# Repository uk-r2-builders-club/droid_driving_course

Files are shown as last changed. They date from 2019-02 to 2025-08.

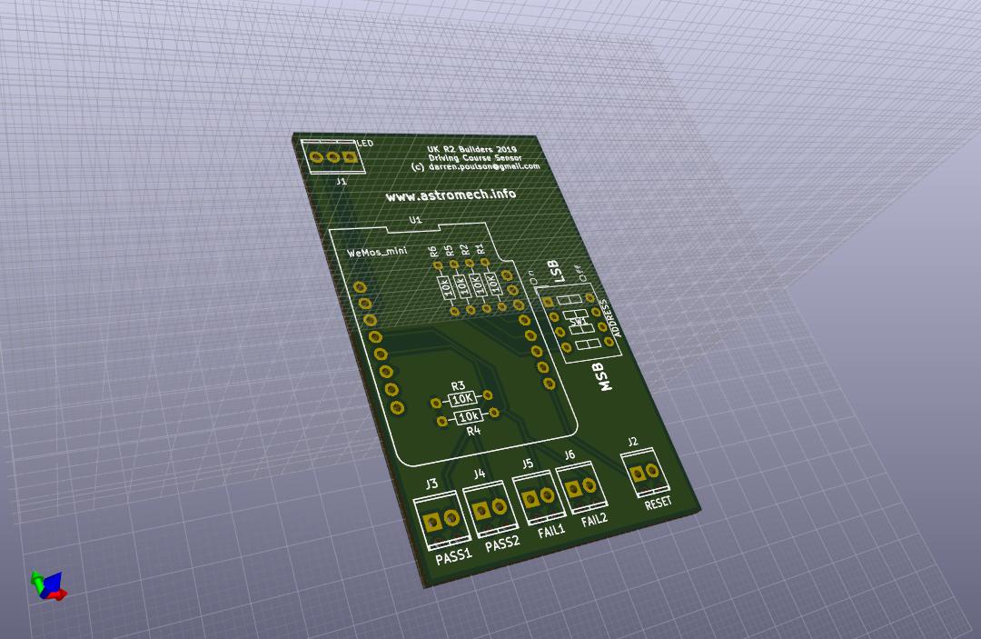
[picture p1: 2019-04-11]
Hardware/Bump Stop/bump_stop.jpg

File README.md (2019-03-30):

This adds an automatic score board system to the UK R2D2 Builders driving course

Existing wired sensors can be replaced with wireless ones, talking back to a central access point and this code running on a Pi. The Pi can have a monitor on it set up to automatically display the scoreboard.

== Installation ==

''' sudo apt-get install git python3-pip python3-future python3-flask '''

''' sudo pip3 install flask-socketio '''

''' mkdir ~/.r2_builders '''

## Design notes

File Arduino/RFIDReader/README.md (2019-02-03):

This code is for a cheap wemos copy using a ESP-WROOM-02, along with an 18650 holder and charger. 

https://www.aliexpress.com/item/WeMos-D1-Esp-Wroom-02-Motherboard-ESP8266-Mini-WiFi-Nodemcu-Module-18650-Battery/32821749383.html

The RFID reader used is:

https://www.aliexpress.com/item/PN532-NFC-RFID-Module-V3-Kits-Reader-Writer/32452824672.html

* GND -> GND
* 3.3 -> VCC
* D2 --> SS 
* D4 --> SCK
* D6 --> MOSI
* D7 --> MISO

config.h needs to be created from the default file. This contains the SSID details for your wifi, along with the base API address.

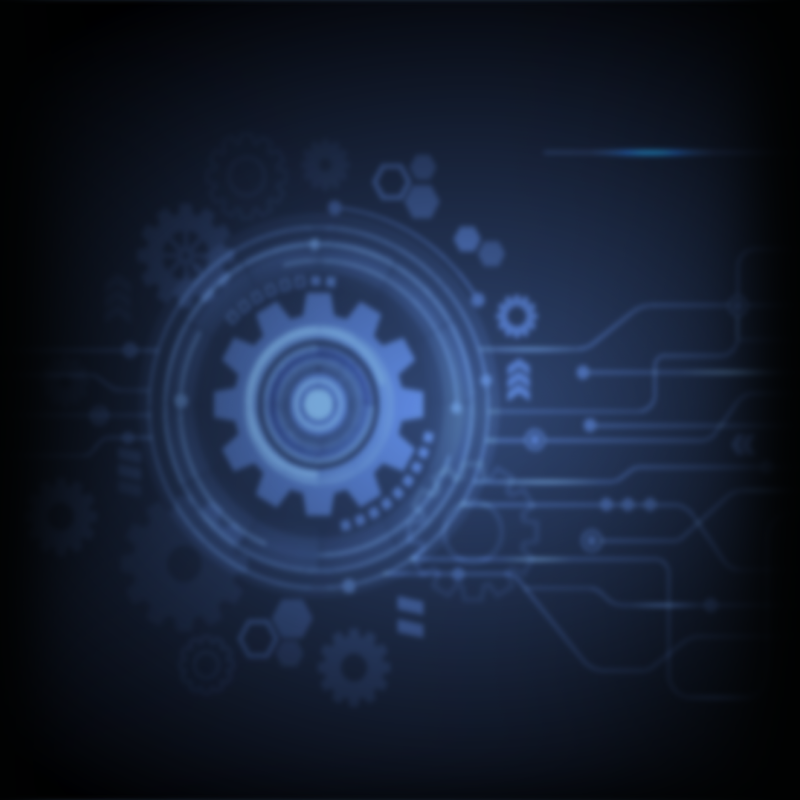
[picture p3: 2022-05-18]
static/images/BGimage.png

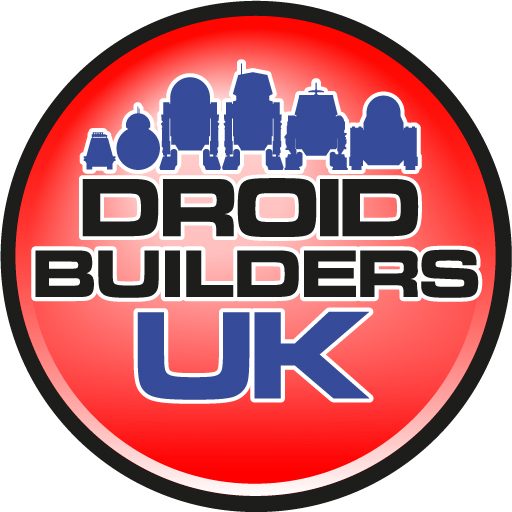
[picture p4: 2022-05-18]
static/cropped-BDround512.jpg

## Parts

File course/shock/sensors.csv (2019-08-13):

id | type | name | penalty
1 | bump | Bump 1 | 20
2 | bump | Bump 2 | 20
3 | gate | Gate 1 | 20
4 | gate | Gate 2 | 20
5 | gate | Gate 3 | 20
6 | bump | Bump 3 | 20
7 | bump | Bump 4 | 20
8 | shock | Shock 1 | 10
9 | shock | Shock 2 | 10

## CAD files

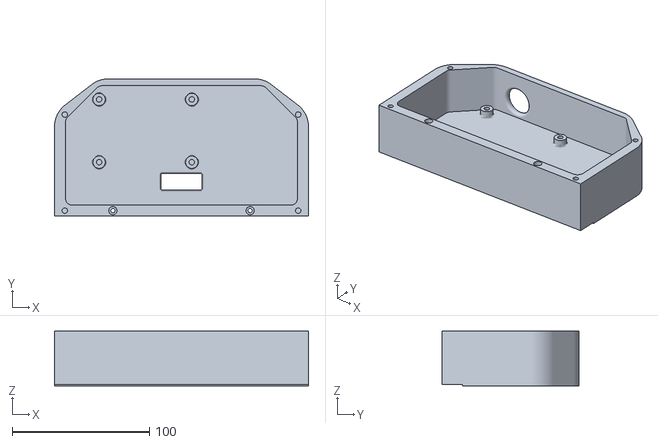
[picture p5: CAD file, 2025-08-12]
Hardware/Bump Stop/bumpstop-Body002Body.stl
185.0 x 100.0 x 40.0

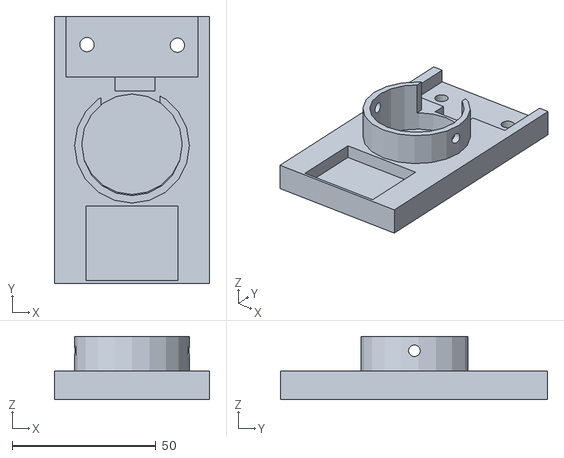
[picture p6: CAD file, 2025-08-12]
Hardware/Timer Gate/Ultrasonic Gate.stl
54.0 x 93.0 x 22.0

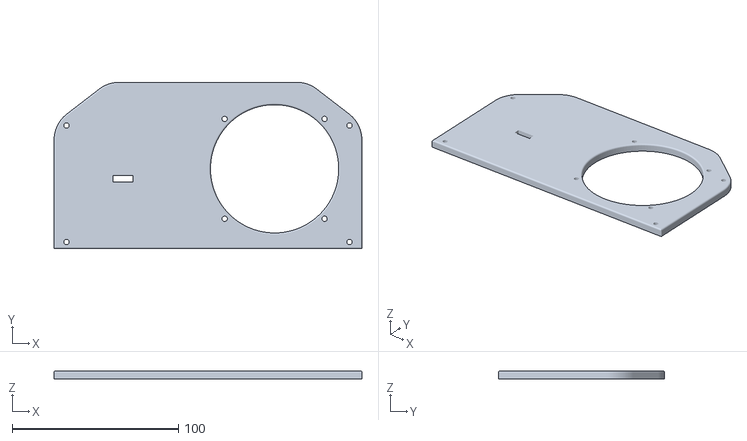
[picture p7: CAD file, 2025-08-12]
Hardware/Bump Stop/bumpstop-LidBody001.stl
185.0 x 100.0 x 5.00

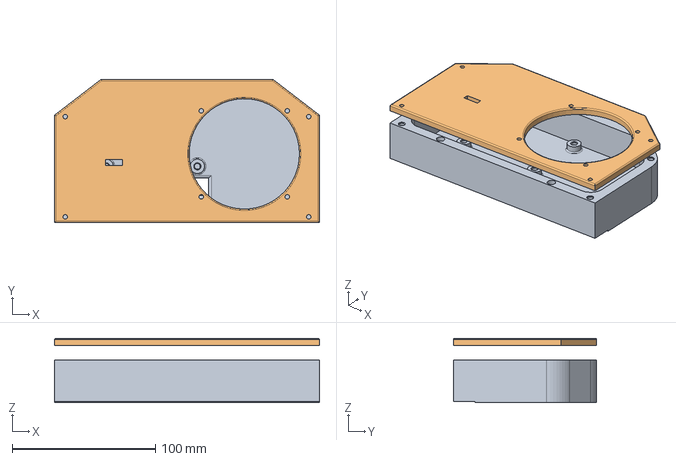
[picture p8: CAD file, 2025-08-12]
Hardware/Bump Stop/bumpstop.FCStd
185.0 x 100.0 x 45.0 mm

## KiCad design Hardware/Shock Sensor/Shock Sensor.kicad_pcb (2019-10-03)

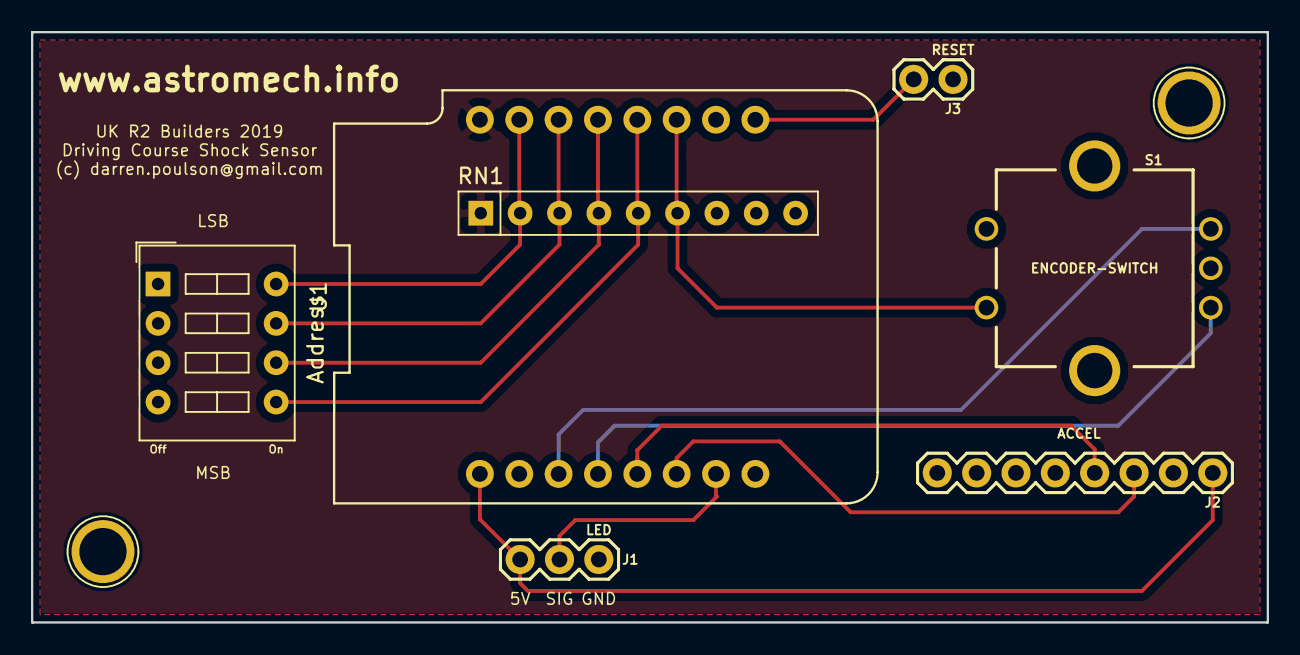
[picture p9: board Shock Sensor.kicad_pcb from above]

Board: 2 copper layers, 79.8 x 38.1 mm, 7 parts (0 on the bottom side), 14 nets.

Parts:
Address: ADDRESS; SW_DIP_x4_W7.62mm_Slide
J1: LED; 1X03
J2: ACCEL; 1X08
J3: RESET; 1X02
RN1: R_Network08; R_Array_SIP9
S1: ENCODER-SWITCH; ROTARY_ENC_PLAIN
U1: WeMos_mini; wemos-d1-mini-with-pin-header-and-connector

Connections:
+3V3: RN1.1, U1.16
+5V: J1.3, J2.1, U1.1
GND: Address.1, Address.2, Address.3, Address.4, J1.1, J2.2, J3.1, S1.C, S1.SW+, U1.2
unnamed: J1.2, U1.7
unnamed: J2.3, U1.6
unnamed: J2.4, U1.5
unnamed: J3.2, U1.9
unnamed: Address.8, RN1.2, U1.15
unnamed: Address.7, RN1.3, U1.14
unnamed: Address.6, RN1.4, U1.13
unnamed: Address.5, RN1.5, U1.12
unnamed: RN1.6, S1.SW-, U1.11
unnamed: S1.A, U1.4
unnamed: S1.B, U1.3

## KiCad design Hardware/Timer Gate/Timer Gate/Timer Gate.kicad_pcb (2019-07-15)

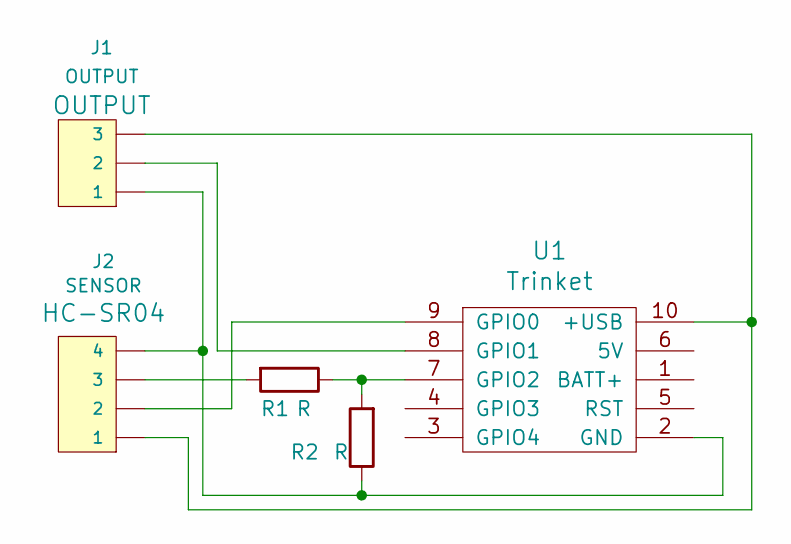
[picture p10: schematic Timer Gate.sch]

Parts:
J1: OUTPUT; 1X03
J2: SENSOR; 1X04
R1, R2: R; R_Axial_DIN0207_L6.3mm_D2.5mm_P7.62mm_Horizontal
U1: Trinket

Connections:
unnamed: J1.1, J2.4, R2.1, U1.2 (GND)
unnamed: J1.2, U1.8 (GPIO1)
unnamed: J1.3, J2.1, U1.10 (+USB)
unnamed: J2.2, U1.9 (GPIO0)
unnamed: J2.3, R1.2
unnamed: R1.1, R2.2, U1.7 (GPIO2)

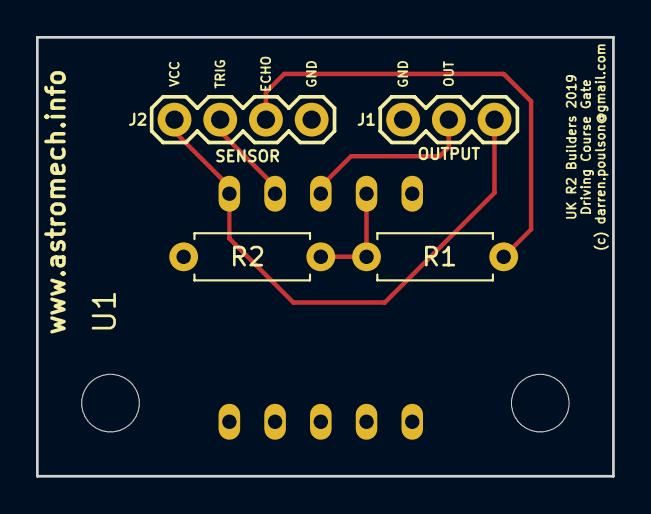
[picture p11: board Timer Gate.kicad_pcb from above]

Board: 2 copper layers, 32.0 x 24.4 mm, 5 parts (0 on the bottom side), 6 nets.

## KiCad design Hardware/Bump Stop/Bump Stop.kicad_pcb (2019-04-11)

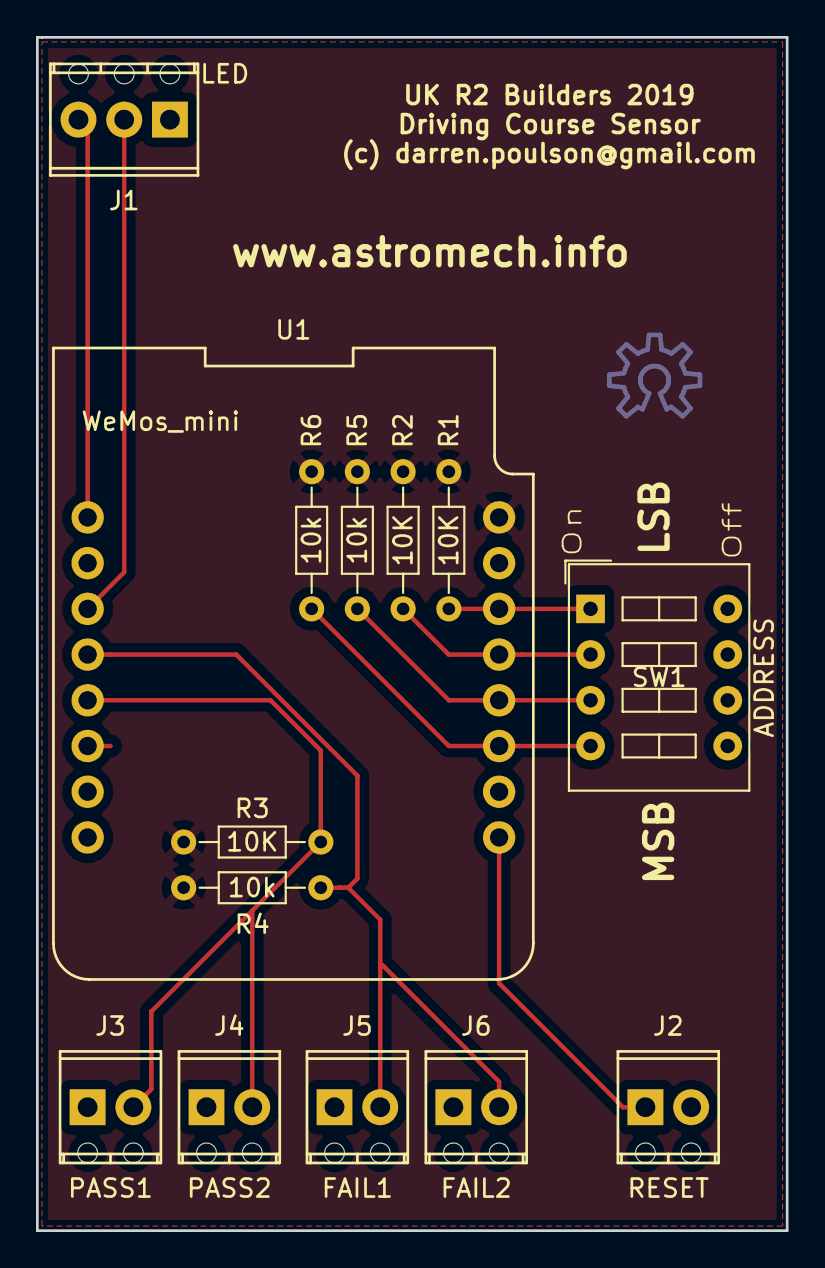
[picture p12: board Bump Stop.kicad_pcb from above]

Board: 2 copper layers, 41.7 x 66.3 mm, 14 parts (0 on the bottom side), 11 nets.

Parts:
J1: LED; TerminalBlock_Phoenix_MPT-2.54mm_3pol
J2: RESET; TerminalBlock_Phoenix_MPT-2.54mm_2pol
J3: PASS1; TerminalBlock_Phoenix_MPT-2.54mm_2pol
J4: PASS2; TerminalBlock_Phoenix_MPT-2.54mm_2pol
J5: FAIL1; TerminalBlock_Phoenix_MPT-2.54mm_2pol
J6: FAIL2; TerminalBlock_Phoenix_MPT-2.54mm_2pol
R1, R2, R3: 10K; R_Axial_DIN0204_L3.6mm_D1.6mm_P7.62mm_Horizontal
R4, R5, R6: 10k; R_Axial_DIN0204_L3.6mm_D1.6mm_P7.62mm_Horizontal
SW1: ADDRESS; SW_DIP_x4_W7.62mm_Slide
U1: WeMos_mini; wemos-d1-mini-with-pin-header

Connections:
+3V3: R1.1, R2.1, R3.1, R4.1, R5.1, R6.1, U1.16
+5V: J1.3, U1.1
GND: J1.1, J2.2, J3.1, J4.1, J5.1, J6.1, SW1.5, SW1.6, SW1.7, SW1.8, U1.2
unnamed: J1.2, U1.3
unnamed: J2.1, U1.9
unnamed: J3.2, J4.2, R3.2, U1.5
unnamed: J5.2, J6.2, R4.2, U1.4
unnamed: R1.2, SW1.1, U1.14
unnamed: R2.2, SW1.2, U1.13
unnamed: R5.2, SW1.3, U1.12
unnamed: R6.2, SW1.4, U1.11

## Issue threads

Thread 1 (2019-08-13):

Repair bump stops

dpoulson, 2019-08-13:
Some LEDs have come unstuck, so need sticking onto the back plate better.

Old style square box bump stop (number 1) looks like it has a broken connection.

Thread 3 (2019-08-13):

Embed timing gates into the aluminium box section.

dpoulson, 2019-08-13:
We should be able to make the timing gates fit into the aluminium box section, either with mods to the current ABS end caps, or fully 3d printed.

Will also need a cap for the existing hole for passing cables through.

Idea is to have the sensor embedded permanently, with a quick connect on the top for the cabling.

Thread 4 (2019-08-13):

Create shock sensors for the uprights.

dpoulson, 2019-08-13:
To try and stop people smashing the course up and actually driving carefully, we want to put some form of sensor on the uprights of the course.

This will probably be an accelerometer with an esp8266 module connected and a string of LEDs for feedback. Possibly also a POT to adjust sensitivity.

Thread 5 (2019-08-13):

Allow multiple types of runs

dpoulson, 2019-08-13:
Have a config option available to change the type of run and what sensors are used on the fly.

This way we can turn off the shock sensors for runs, for example.

It must also keep a track of what course type is used for each run, for the leaderboard.

dpoulson, 2019-08-14:
Added ability to change course type.

https://github.com/uk-r2-builders-club/droid_driving_course/commit/cd7b19e16ff1c50490b2dbd8aac8ee889621bee7

Under directory ./course/ create a directory with the name of the course type, and add a sensors.csv file to it with sensor data.

Closed 2019-08-14.

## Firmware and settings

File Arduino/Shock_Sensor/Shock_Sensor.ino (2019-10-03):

#include <Bounce2.h>
#include "I2Cdev.h"
#include "MPU6050.h"
#include <ArduinoOTA.h>
#include <ESP8266WiFi.h>
#include <ESP8266WiFiMulti.h>
#include <ESP8266HTTPClient.h>
#include <WiFiClient.h>
#include <Adafruit_NeoPixel.h>
#include <WiFiUdp.h>
#include <EEPROM.h>

#include "config.h"

#if I2CDEV_IMPLEMENTATION == I2CDEV_ARDUINO_WIRE
    #include "Wire.h"
#endif

const byte address_bits[] =  { 13,12,14,16 };
const int lighttime = 10000;
unsigned int address;
unsigned int localPort = 8888;
char packetBuffer[64]; //buffer to hold incoming packet,
char  ReplyBuffer[] = "acknowledged\r\n";       // a string to send back
int sensitivity = 11000;
int eeAddress = 0; 
bool inCalibration = false;

#define CELEBRATION     10
#define LED_PIN         3                        // Neopixel string data in pin
#define LED_COUNT       8                        // Number of neopixels
#define CALIBRATION_PIN 16                       // Input pin for push button on rotary encoder
#define encoder0PinA    2                        // Input for one direction of rotary encoder
#define encoder0PinB    0                        // Input pin for the other direction of the rotary encoder
#define SENSE_SCALE     100                      // How much sensitivity will change per click
#define SENSE_MIN       5000                     // Minimum sensitivity
#define SENSE_MAX       13000                    // Maximum sensitivity
#define MAG_MID         5000                     // Magnitude mid point
#define SHOCK_INTERVAL  500                      // How often the shock peak will decrease
#define SHOCK_DECREASE  1000                     // How much the shock peak will decrease with each SHOCK_INTERVAL

MPU6050 accelgyro;
int16_t ax, ay, az;
int16_t gx, gy, gz;
int32_t shock_peak;
int32_t shock_show;
long last_peak;

WiFiUDP Udp;
ESP8266WiFiMulti WiFiMulti;
WiFiClient client;
HTTPClient http;

Adafruit_NeoPixel strip(LED_COUNT, LED_PIN, NEO_GRB + NEO_KHZ800);

uint32_t led_red    = strip.Color(255,0,0);
uint32_t led_orange = strip.Color(255,165,0);
uint32_t led_green  = strip.Color(0,255,0);
uint32_t led_blue   = strip.Color(0,0,255);
uint32_t led_off    = strip.Color(0,0,0);

Bounce debouncer = Bounce();
void ICACHE_RAM_ATTR doEncoderA();
void ICACHE_RAM_ATTR doEncoderB();

long timer = 0;

void setup() {
  Serial.begin(115200);
  Serial.println("Startup");
  pinMode(CALIBRATION_PIN,INPUT_PULLUP);
  debouncer.attach(CALIBRATION_PIN);
  debouncer.interval(25);

  pinMode(encoder0PinA, INPUT);
  pinMode(encoder0PinB, INPUT);

  // encoder pin on interrupt 0 (pin 2)
  attachInterrupt(0, doEncoderA, CHANGE);

  // encoder pin on interrupt 1 (pin 3)
  attachInterrupt(1, doEncoderB, CHANGE);
  
  for (byte x = 0 ; x < 4 ; x ++ ) {
    Serial.print("Configuring Pin: ");
    Serial.println(address_bits[x]);
    pinMode(address_bits[x], INPUT);
  }

  Serial.println("Read in address");
  for (byte x = 0 ; x < 4 ; x ++ ) {
    byte value = !digitalRead(address_bits[x]);
    Serial.print("Bit: ");
    Serial.print(x);
    Serial.print(" Value: ");
    Serial.println(value);
    address = address + (value << x);
  }
  address = address + 16; // Shock sensors are in the second block of 16 sensors.
  Serial.print("Address: ");
  Serial.println(address);

  strip.begin();
  strip.setBrightness(70);
  strip.show();
 

  // Check for a stored value for sensitivity, and read it. Or use the default if it isn't present
  int s;
  Serial.print("EEPROM Stored sensitivity: ");
  EEPROM.begin(512);
  EEPROM.get(eeAddress, s);
  Serial.println(s);
  if (s > SENSE_MIN && s < SENSE_MAX) {
    Serial.println("Setting sensitivity from EEPROM");
    sensitivity = s;
  } else {
    Serial.println("Storing default sensitivity in EEPROM");
    EEPROM.put(eeAddress, sensitivity);
    EEPROM.commit();
  }
  
  char sensor_name[20];
  sprintf(sensor_name, "shock_sensor%02d", address);
  WiFi.mode(WIFI_STA);
  WiFi.hostname(sensor_name);
  WiFiMulti.addAP(ssid, pass);

  int timeout = 0;
  while (WiFiMulti.run() != WL_CONNECTED) {
     delay(100);
     Serial.print("Connecting..");
     pulseLights();
     timeout ++;
     if (timeout > 30) {
        break;
     }
  }
  if ((WiFiMulti.run() == WL_CONNECTED)) {
     Serial.println("Connected!");
     startupLights();
     strip.fill(strip.Color(0, 0, 0),0,LED_COUNT);
     strip.show();
  } else {
     Serial.println("TIMEOUT!");
     flashLights(10, 100);
     strip.fill(strip.Color(0, 0, 0),0,LED_COUNT);
     strip.show();     
  }
  Udp.begin(localPort);

  ArduinoOTA.setHostname(sensor_name);
  ArduinoOTA.onStart([]() {
    Serial.println("Start");
  });
  ArduinoOTA.onEnd([]() {
    Serial.println("\nEnd");
  });
  ArduinoOTA.onProgress([](unsigned int progress, unsigned int total) {
    Serial.printf("Progress: %u%%\r", (progress / (total / 100)));
  });
  ArduinoOTA.onError([](ota_error_t error) {
    Serial.printf("Error[%u]: ", error);
    if (error == OTA_AUTH_ERROR) Serial.println("Auth Failed");
    else if (error == OTA_BEGIN_ERROR) Serial.println("Begin Failed");
    else if (error == OTA_CONNECT_ERROR) Serial.println("Connect Failed");
    else if (error == OTA_RECEIVE_ERROR) Serial.println("Receive Failed");
    else if (error == OTA_END_ERROR) Serial.println("End Failed");
  });
  ArduinoOTA.begin();


  // join I2C bus (I2Cdev library doesn't do this automatically)
  #if I2CDEV_IMPLEMENTATION == I2CDEV_ARDUINO_WIRE
      Wire.begin();
  #elif I2CDEV_IMPLEMENTATION == I2CDEV_BUILTIN_FASTWIRE
      Fastwire::setup(400, true);
  #endif
 
  accelgyro.initialize();
  Serial.println(accelgyro.testConnection() ? "MPU6050 connection successful" : "MPU6050 connection failed");
  delay(500);
  
  accelgyro.setXAccelOffset(1250);
  accelgyro.setYAccelOffset(500);
  accelgyro.setZAccelOffset(-16000);  
  
}

void loop() {
  debouncer.update();

  if ( debouncer.fell() ) {  // Call code if button transitions from HIGH to LOW
     inCalibration = !inCalibration;
     startupLights();
     Serial.println("Toggle calibration mode");     
     EEPROM.put(eeAddress, sensitivity);
     EEPROM.commit();
  }

  if (millis() > last_peak + SHOCK_INTERVAL) {
    shock_peak = shock_peak - SHOCK_DECREASE;
    shock_leds();
    last_peak = millis();
  }
  
  if (!inCalibration) {
    accelgyro.getMotion6(&ax, &ay, &az, &gx, &gy, &gz);
    long int mag = (sqrt((ax * ax)/10 + (ay * ay)/10 + (az * az)/10)) - MAG_MID;
    if (mag > shock_peak) {
      shock_peak = mag;
      last_peak = millis();
      int lit_leds = mag/((sensitivity)/LED_COUNT);
      shock_leds();
    }
    
    Serial.print("Magnitude: ");
    Serial.print(mag);

    if (mag < 0 ) {
      mag = mag * -1;
    }

    if (mag > sensitivity) {
      Serial.println("SHOCK!!!!!!!!");
      Serial.print("Magnitude: ");
      Serial.println(mag);
      String api_call = String((char*)api) + "gate/" + address + "/FAIL";
      Serial.print("API Call: ");
      Serial.println(api_call);
      http.begin(client, api_call);
      int httpCode = http.GET();
      http.end();      
      delay(5000);
      Serial.println("Continuing monitoring");
    }
    Serial.print("/");
    Serial.print(mag);
    Serial.print("\t");
    Serial.print(ax); Serial.print("\t");
    Serial.print(ay); Serial.print("\t");
    Serial.print(az); Serial.print("\t");
    Serial.print(shock_peak); Serial.print("\t");
    Serial.println(shock_show); 
  } else {
    // Calculate the number of LEDs to light
    int lit_leds = (sensitivity - SENSE_MIN)/((SENSE_MAX-SENSE_MIN)/LED_COUNT);
    
    Serial.print("Sensitivity: ");
    Serial.print(sensitivity);
    Serial.print(" LEDs to light: ");
    Serial.println(lit_leds);
    calibrate_leds(lit_leds);
  }
}

void calibrate_leds(int lit_leds) {
  // Light up 'lit_leds' to show calibration level
  for (int i = 0; i < LED_COUNT; i++) {
    if (i < lit_leds) {
      strip.setPixelColor(i, led_blue);
    } else {
      strip.setPixelColor(i, led_off);
    }
  }
  strip.show();
}

void shock_leds() {
    int lit_leds = shock_peak/((sensitivity)/LED_COUNT);
    int l;
    for (l = 0 ; l < LED_COUNT; l++) {
      uint32_t colour = led_green;       // Default to LED being green
      if (l > (LED_COUNT/2) - 1) {       // If it is over half way, make the LED orange
        colour = led_orange;
      }
      if (l == LED_COUNT - 1) {           // If its the final LED then it should be red
        colour = led_red;
      }
      if (l < lit_leds) {
        strip.setPixelColor(l, colour);
      } else {
        strip.setPixelColor(l, led_off);
      }
    }
    strip.show(); 
}

void changePos(int x) {
  sensitivity = (sensitivity+(x*SENSE_SCALE));
  if (sensitivity > SENSE_MAX)
      sensitivity = SENSE_MAX;
  if (sensitivity < SENSE_MIN)
      sensitivity = SENSE_MIN;
}

void doEncoderA() {
  // look for a low-to-high on channel A
  if (digitalRead(encoder0PinA) == HIGH) {
    // check channel B to see which way encoder is turning
    if (digitalRead(encoder0PinB) == LOW) 
      changePos(1);          // CW
    else 
      changePos(-1);         // CCW
  } else {
    // must be a high-to-low edge on channel A
    // check channel B to see which way encoder is turning
    if (digitalRead(encoder0PinB) == HIGH) 
      changePos(1);          // CW
    else 
      changePos(-1);         // CCW
  }
}

void doEncoderB() {
  // look for a low-to-high on channel B
  if (digitalRead(encoder0PinB) == HIGH) {
    // check channel A to see which way encoder is turning
    if (digitalRead(encoder0PinA) == HIGH) 
      changePos(1);          // CW
    else 
      changePos(-1);         // CCW
  } else {
    // Look for a high-to-low on channel B
    // check channel B to see which way encoder is turning
    if (digitalRead(encoder0PinA) == LOW) 
      changePos(1);          // CW
    else 
      changePos(-1);         // CCW
  }
}


void flashLights(int count, int wait) {
  int i;
  for(i=0; i<count; i++) {
     strip.fill(strip.Color(255,0,0),0,LED_COUNT);
     strip.show();
     delay(wait);
     strip.fill(strip.Color(0,0,0),0,LED_COUNT);
     strip.show();
     delay(wait);
  }
}


uint32_t Wheel(byte WheelPos) {
  WheelPos = 255 - WheelPos;
  if(WheelPos < 85) {
    return strip.Color(255 - WheelPos * 3, 0, WheelPos * 3);
  }
  if(WheelPos < 170) {
    WheelPos -= 85;
    return strip.Color(0, WheelPos * 3, 255 - WheelPos * 3);
  }
  WheelPos -= 170;
  return strip.Color(WheelPos * 3, 255 - WheelPos * 3, 0);
}

void pulseLights() {
   uint16_t i, j;
   for(i=0; i<50; i++) {
     strip.fill(strip.Color(i*5,0,0), 0, LED_COUNT);
     strip.show();
     delay(5);
   }
   for(j=50; j>0; j--) {
     strip.fill(strip.Color(j*5,0,0), 0, LED_COUNT);
     strip.show();
     delay(5);
   }  
}

void startupLights() {
  uint16_t i, j;

  for(j=0; j<256; j++) {
    for(i=0; i<9; i++) {
      strip.fill(Wheel((i+j) & 255),0,LED_COUNT);
    }
    strip.show();
    delay(5);
  }
  strip.clear();
  strip.show();
}

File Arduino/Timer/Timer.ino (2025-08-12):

#define USE_FASTLED 1
#ifdef USE_FASTLED
 #include <FastLED.h>
#else
 #include <Adafruit_NeoPixel.h>
#endif

#include <Arduino.h>
#include <Bounce2.h>

#include <WiFi.h>
#include <WiFiMulti.h>
#include <WiFiUdp.h>
#include <ArduinoOTA.h>

#include <HTTPClient.h>
#include "config.h"

#define USE_SERIAL Serial
#define DIGITS 5

// "WeMos" WiFi&Bluetooth Battery, 80Mhz, 921600

////////////////////////////////////////////////////////////////////////////////
#define NUMPIXELS 43 // Number of LEDs in a strip (some are actually 56, 
#define DATAPIN0 14 //digit 0 NeoPixel 60 strip far RIGHT
#define DATAPIN1 32 //digit 1 (plus lower colon dot)
#define DATAPIN2 15 //digit 2 (plus upper colon dot)
#define DATAPIN3 33 //digit 3 (plus decimal dot)
#define DATAPIN4 27 //digit 4 far LEFT
const int pins[DIGITS] = { 14, 32, 15, 33, 27 };


#ifdef USE_FASTLED
 CRGB strip[DIGITS][NUMPIXELS];
#else

Adafruit_NeoPixel strip[] = { //here is the variable for the multiple strips
  Adafruit_NeoPixel(NUMPIXELS, pins[0], NEO_GRB + NEO_KHZ800),
  Adafruit_NeoPixel(NUMPIXELS, pins[1], NEO_GRB + NEO_KHZ800),
  Adafruit_NeoPixel(NUMPIXELS, pins[2], NEO_GRB + NEO_KHZ800),
  Adafruit_NeoPixel(NUMPIXELS, pins[3], NEO_GRB + NEO_KHZ800),
  Adafruit_NeoPixel(NUMPIXELS, pins[4], NEO_GRB + NEO_KHZ800)
};
#endif
const int bright = 200; //adjust brightness for all pixels 0-255 range,
// 32 being pretty dim, 255 being full brightness

#define DEBOUNCE 10
#define FLASHINTERVAL 500

#define RESETPIN 26
#define STARTPIN 25
#define PAUSEPIN 34
#define RESUMEPIN 19
#define STOPPIN 18

#define CELEBRATION 10

const int segments[10][8] = {
  { 1,1,1,1,1,1,0,1 },
  { 0,0,1,1,0,0,0,1 },
  { 0,1,1,0,1,1,1,1 },
  { 0,1,1,1,1,0,1,1 },
  { 1,0,1,1,0,0,1,1 },
  { 1,1,0,1,1,0,1,1 },
  { 1,1,0,1,1,1,1,1 },
  { 0,1,1,1,0,0,0,1 },
  { 1,1,1,1,1,1,1,1 },
  { 1,1,1,1,1,0,1,1 },
};

const int colours[11][3] = {
  { 0, 0, 0 },
  { 255,0,0 },
  { 0,255,0 },
  { 0,0,255 },
  { 160,160,160 },
  { 255,255,0 },
  { 255,0,255 },
  { 255,255,0 },
  { 0,255,255 },
  { 175,0,255 },
  { 0, 0, 255 }   
};

// segs are 0-5, 6-11, 12-17, 18-23, 24-29, 30-35, 36-41, 42
const int segs[8][2] {
  { 0, 5 },
  { 6, 11 },
  { 12, 17 },
  { 18, 23 },
  { 24, 29 },
  { 30, 35 },
  { 36, 41 },
  { 42, 42 }
};

#define NUM_BUTTONS 5
const uint8_t BUTTON_PINS[NUM_BUTTONS] = { RESETPIN, STARTPIN, PAUSEPIN, RESUMEPIN, STOPPIN };

Bounce * buttons = new Bounce[NUM_BUTTONS];
String pressed = "";
char display_time[DIGITS + 1] = "00000";
char last_display[DIGITS + 1] = "00000";
unsigned int localPort = 8888;
char packetBuffer[64]; //buffer to hold incoming packet,
char  ReplyBuffer[] = "acknowledged\r\n";       // a string to send back

unsigned long course_time;
unsigned long last_flash;
unsigned long start_time;
int course_state = 0;
int clock_colour = 1;
int clock_flash = 0;
int clock_flash_state = LOW;

WiFiUDP Udp;
WiFiMulti WiFiMulti;
HTTPClient http;
////////////////////////////////////////////////////////////////////////////////

void setup() {
////////////////////////////////////////////////////////////////////////////////
  byte i;
  USE_SERIAL.begin(115200);
  
  for (int i = 0; i < NUM_BUTTONS; i++) {
    buttons[i].attach( BUTTON_PINS[i] , INPUT_PULLUP  );       //setup the bounce instance for the current button
    buttons[i].interval(25);              // interval in ms
  }
  
  WiFi.mode(WIFI_STA);
  WiFiMulti.addAP(ssid, pass);

  // allow reuse (if server supports it)

  delay(500); //pause a moment to let capacitors on board settle

  #ifdef USE_FASTLED
  FastLED.addLeds<NEOPIXEL, DATAPIN0>(strip[0], NUMPIXELS);
  FastLED.addLeds<NEOPIXEL, DATAPIN1>(strip[1], NUMPIXELS);
  FastLED.addLeds<NEOPIXEL, DATAPIN2>(strip[2], NUMPIXELS);
  FastLED.addLeds<NEOPIXEL, DATAPIN3>(strip[3], NUMPIXELS);
  FastLED.addLeds<NEOPIXEL, DATAPIN4>(strip[4], NUMPIXELS);

  //flash an zero
  for(int t=0;t<DIGITS;t++){
    digitWrite(t,0,0); //clear it
    FastLED.show();
    digitWrite(t,0,1); //display it
    FastLED.show();
  }   
  
  #else
  //NeoPixel array setup
  for(int s=0;s<DIGITS;s++){
    strip[s].begin(); // Initialize pins for output
    strip[s].setBrightness(bright);
    strip[s].show();
    delay(200);
  }    
  //flash an zero
  for(int t=0;t<DIGITS;t++){
    digitWrite(t,0,0); //clear it
    strip[t].show();
    digitWrite(t,0,1); //display it
    strip[t].show();
  }
  #endif
  int timeout = 0;
  while (WiFiMulti.run() != WL_CONNECTED) {
     delay(1000);
     Serial.print("Connecting..");
     timeout ++;
     if (timeout > 120) {
        break;
     }
  }
  if ((WiFiMulti.run() == WL_CONNECTED)) {
     Serial.println("Connected!");
     rainbowLights();
  } else {
     Serial.println("TIMEOUT!");
  }
    http.setReuse(true);
  Udp.begin(localPort);

  ArduinoOTA.setHostname("timer");
  ArduinoOTA.onStart([]() {
    Serial.println("Start");
  });
  ArduinoOTA.onEnd([]() {
    Serial.println("\nEnd");
  });
  ArduinoOTA.onProgress([](unsigned int progress, unsigned int total) {
    Serial.printf("Progress: %u%%\r", (progress / (total / 100)));
  });
  ArduinoOTA.onError([](ota_error_t error) {
    Serial.printf("Error[%u]: ", error);
    if (error == OTA_AUTH_ERROR) Serial.println("Auth Failed");
    else if (error == OTA_BEGIN_ERROR) Serial.println("Begin Failed");
    else if (error == OTA_CONNECT_ERROR) Serial.println("Connect Failed");
    else if (error == OTA_RECEIVE_ERROR) Serial.println("Receive Failed");
    else if (error == OTA_END_ERROR) Serial.println("End Failed");
  });
  ArduinoOTA.begin();
//END void setup()
////////////////////////////////////////////////////////////////////////////////
}
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

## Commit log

2019-02-01 A few tweaks, and added Arduino code for RFID reader
2019-02-03 Lots of little tweaks, and cut down on some unneeded code in the RFID reader
2019-02-03 Added Gates to scoreboard, and a basic admin page
    [gates.csv]
2019-02-04 RFID reader now has a buzzer, and all results can now be uploaded to the MOT site
    [RFIDReader.ino, database.py, main.py]
2019-02-25 Updated RFID to use TTGO board with built in speaker and 1.4 inch TFT
2019-03-21 Update of arduino code
2019-04-09 Bump sensor hardware and code update
    [Bump Stop-B.Cu.gbl, Bump Stop-B.Mask.gbs, Bump Stop-B.Paste.gbp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]
2019-04-11 Load of updates, and some tools for reading RFID cards
    [standard.csv]
2019-04-17 Updates to the bump sensor sketch and schematics
    [Bump Stop.sch, _saved_Bump Stop.sch]
2019-05-12 Timing is now handled by the main clock, and its internal arduino. This is much more reliable
2019-05-12 Updates to main timer code, and added in course gate schematic and board
    [Timer Gate-B.Cu.gbr, Timer Gate-B.Mask.gbr, Timer Gate-B.Paste.gbr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]
2019-05-31 Added PCB for Timer Gate
    [Timer Gate.kicad_pcb]
2019-07-14 Updated course gate PCB, and updated the strobe code
    [Timer Gate-B.Cu.gbr, Timer Gate-B.Mask.gbr, Timer Gate-B.Paste.gbr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]
2019-07-15 Added ability to read DHCP leases to see connected devices
2019-07-15 Some clean up and a few tweaks to arduino code
2019-08-04 A few bug fixes
    [broadcast.py, main.py]
2019-08-12 Added today results page, and fixed bug where penalties were able to be added even after the run had finished
    [database.py, main.py]
2019-08-12 Added initial structure for Shock Sensor
2019-08-13 Added config options to the database, rather than an ini file. Also started on adding different course types
    [config.csv, sensors.csv]
2019-08-13 Added audio library (from r2_control) and now and failed gate sets off a siren
    [config.csv]
2019-08-14 Added support for switching course layouts
    [config.csv]
2019-09-19 A few tweaks and comments to arduino code. Also started on shock sensor code
    [Shock Sensor.kicad_pcb, Shock Sensor.sch]
2019-09-20 Bunch of work on the shock sensor. Calibration works, and fixed a math overflow issue
    [Shock_Sensor.ino]
2019-10-03 Updates to PCB and code for shock sensors
    [Shock Sensor-B.Cu.gbr, Shock Sensor-B.Mask.gbr, Shock Sensor-B.Paste.gbr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]
2022-05-18 Bunch of fixes, and moved bootstrap and JS requirements into repo for offline use
    [config.csv]
2022-08-15 Some emergency fixes done at DBUK 2022
    [config.csv]
2022-08-15 Fixes to the course upload to the portal.
    [main.py]
2025-08-12 Updated bump stops
    [Bump Stop-B.Cu.gbl, Bump Stop-B.Mask.gbs, Bump Stop-B.Paste.gbp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]
